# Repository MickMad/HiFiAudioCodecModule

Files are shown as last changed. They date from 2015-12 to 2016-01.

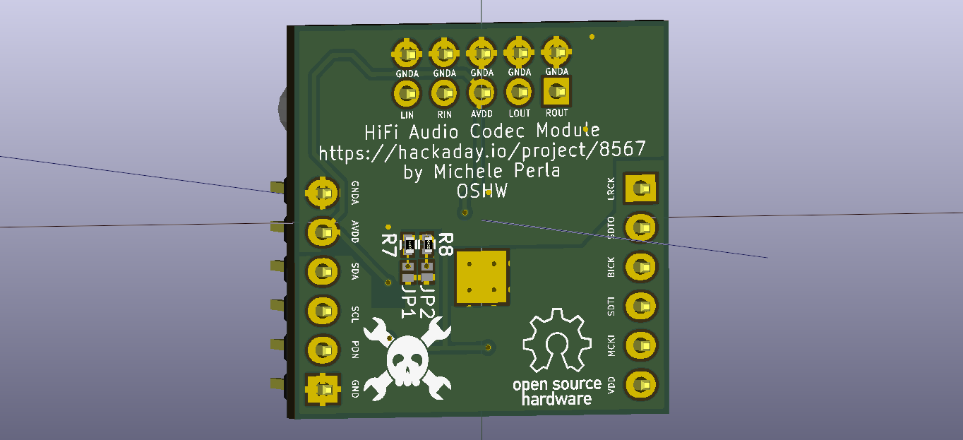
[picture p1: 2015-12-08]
graphics/HiFiAudioCodecModule - 3D - bottom.png

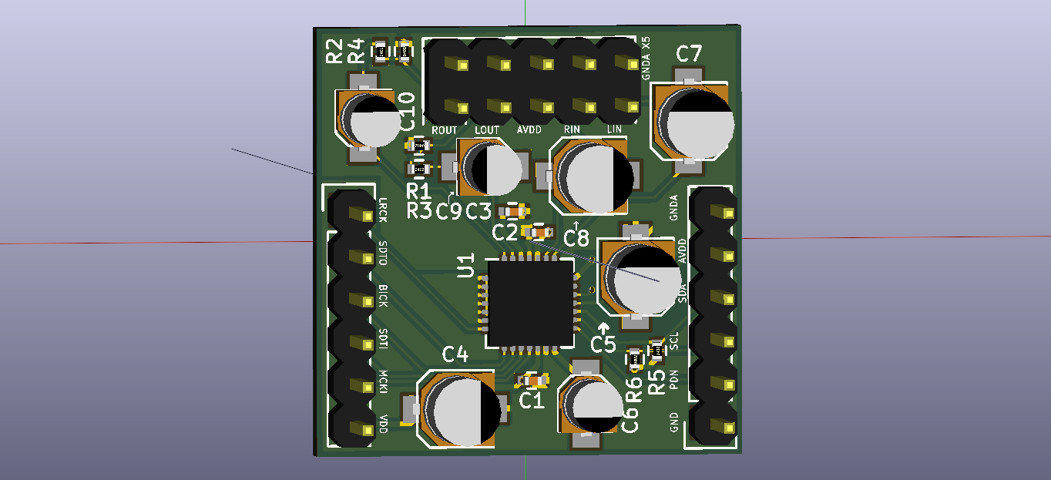
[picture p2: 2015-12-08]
graphics/HiFiAudioCodecModule - 3D - top.png

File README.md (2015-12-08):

#HiFi Audio Codec Module
##A very small hifi audio codec module

The purpose of this project is to create a small (1 square inch board size) HiFi audio CODEC module to be used with I2S-compatible MCUs

More info here: 
https://hackaday.io/project/8567-hifi-audio-codec-module

The project is a submission for the following contest (The Square Inch project): 
https://hackaday.io/project/7813-the-square-inch-project

```
Copyright © Michele Perla 2015

This documentation describes Open Hardware and is licensed under the CERN OHL v. 1.2.
You may redistribute and modify this documentation under the terms of the CERN OHL v.1.2. 
(http://ohwr.org/cernohl). This documentation is distributed
WITHOUT ANY EXPRESS OR IMPLIED WARRANTY, INCLUDING OF
MERCHANTABILITY, SATISFACTORY QUALITY AND FITNESS FOR A
PARTICULAR PURPOSE. Please see the CERN OHL v.1.2 for applicable
conditions
```

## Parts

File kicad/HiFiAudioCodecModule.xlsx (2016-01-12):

 |  |  |  |  |  |  | Board Qty: | 100
 |  |  |  |  |  |  | Total Cost: | $0.00 |  |  |  | $0.00 |  |  |  |  |  | $0.00 |  |  |  |  |  | $0.00
 |  |  |  |  |  |  | Unit Cost: | $0.00
Global Part Info |  |  |  |  |  |  |  |  | Digi-Key |  |  |  |  |  | Mouser |  |  |  |  |  | Newark
Refs | Value | Desc | Footprint | Manf | Manf# | Qty | Unit$ | Ext$ | Avail | Purch | Unit$ | Ext$ | Cat# | Doc | Avail | Purch | Unit$ | Ext$ | Cat# | Doc | Avail | Purch | Unit$ | Ext$ | Cat# | Doc
JP1,JP2 | Jumper_NO_Small |  | HiFiAudioCodecModule-footprints:SMD_Jumper |  |  | 0 | $0.00 | $0.00
LOGO1 | OSHW |  | oshw_logo:LOGO |  |  | 0 | $0.00 | $0.00
C3 | 1u |  | HiFiAudioCodecModule-footprints:C_0402 |  | CC0402KRX7R5BB105 | 0 | $0.00 | $0.00 | 1 |  | $0.00 | $0.00 | 311-1702-1-ND | Link (http://www.digikey.com/product-detail/en/CC0402KRX7R5BB105/311-1702-1-ND/5195604) | 0 |  | $0.00 | $0.00 | 603-CC402KRX7R5BB105 | Link (http://www.mouser.com/Search/Refine.aspx?Keyword=CC0402KRX7R5BB105) | 0 |  | $0.00 | $0.00 | 55X1892 | Link (http://www.newark.com/webapp/wcs/stores/servlet/Search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)
P1,P2 | CONN_01X06 |  | HiFiAudioCodecModule-footprints:Pin_Header_Straight_1x06 |  | M20-9990645 | 0 | $0.00 | $0.00 | 13820 |  | $0.00 | $0.00 | 952-2269-ND | Link (http://www.digikey.com/scripts/DkSearch/dksus.dll?WT.z_header=search_go&lang=en&keywords=M20-9990645) | 6668 |  | $0.00 | $0.00 | 855-M20-9990645 | Link (http://www.mouser.com/Search/Refine.aspx?Keyword=M20-9990645) | 8231 |  | $0.00 | $0.00 | 97K6212 | Link (http://www.newark.com/webapp/wcs/stores/servlet/Search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)
R1,R2 | 220 |  | HiFiAudioCodecModule-footprints:R_0402 |  | RC0402FR-07220RL | 0 | $0.00 | $0.00 | 345265 |  | $0.00 | $0.00 | 311-220LRCT-ND | Link (http://www.digikey.com/product-detail/en/RC0402FR-07220RL/311-220LRCT-ND/729512) | 135033 |  | $0.00 | $0.00 | 603-RC0402FR-07220RL | Link (http://www.mouser.com/Search/Refine.aspx?Keyword=RC0402FR-07220RL) | 12940 |  | $0.00 | $0.00 | 67R9914 | Link (http://www.newark.com/yageo/rc0402fr-07220rl/res-thick-film-220r-1-0-0625w/dp/67R9914)
R5-R8 | 1K |  | HiFiAudioCodecModule-footprints:R_0402 |  | RC0402FR-071KL | 0 | $0.00 | $0.00 | 4418858 |  | $0.00 | $0.00 | 311-1.00KLRCT-ND | Link (http://www.digikey.com/product-detail/en/RC0402FR-071KL/311-1.00KLRCT-ND/729460) | 995543 |  | $0.00 | $0.00 | 603-RC0402FR-071KL | Link (http://www.mouser.com/Search/Refine.aspx?Keyword=RC0402FR-071KL) | 7873 |  | $0.00 | $0.00 | 67R9877 | Link (http://www.newark.com/yageo/rc0402fr-071kl/res-thick-film-1k-1-0-0625w-0402/dp/67R9877)
C4,C5 | 10u |  | HiFiAudioCodecModule-footprints:CAP_ELEC_SMD_3x5mm |  | UWX1C100MCL2GB | 0 | $0.00 | $0.00 | 147265 |  | $0.00 | $0.00 | 493-2099-1-ND | Link (http://www.digikey.com/product-detail/en/UWX1C100MCL2GB/493-2099-1-ND/590074) | 23076 |  | $0.00 | $0.00 | 647-UWX1C100MCL2 | Link (http://www.mouser.com/Search/Refine.aspx?Keyword=UWX1C100MCL2GB) | 1079 |  | $0.00 | $0.00 | 58R3619 | Link (http://www.newark.com/nichicon/uwx1c100mcl2gb/aluminum-electrolytic-capacitor/dp/58R3619)
U1 | AK4558EN |  | HiFiAudioCodecModule-footprints:QFN-28-2xEP_5x5mm_Pitch0.5mm |  | AK4558EN | 0 | $0.00 | $0.00 | 2833 |  | $0.00 | $0.00 | 974-1083-1-ND | Link (http://www.digikey.com/product-detail/en/AK4558EN/974-1083-1-ND/5322946)
LOGO2 | HACKADAY |  | hackaday_logo:LOGO |  |  | 0 | $0.00 | $0.00
C7,C8 | 10u |  | HiFiAudioCodecModule-footprints:C_Radial_D5_L11_P2-bipolar |  | UES1E100MDM1TD | 0 | $0.00 | $0.00 | 9451 |  | $0.00 | $0.00 | 493-10824-1-ND | Link (http://www.digikey.com/product-detail/en/UES1E100MDM1TD/493-10824-1-ND/4317799) | 1858 |  | $0.00 | $0.00 | 647-UES1E100MDM1TD | Link (http://www.mouser.com/Search/Refine.aspx?Keyword=UES1E100MDM1TD) | 0 |  | $0.00 | $0.00 | 58R7475 | Link (http://www.newark.com/webapp/wcs/stores/servlet/Search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)
C1,C2 | 0.1u |  | HiFiAudioCodecModule-footprints:C_0402 |  | CC0402KRX7R7BB104 | 0 | $0.00 | $0.00 | 2903130 |  | $0.00 | $0.00 | 311-1338-1-ND | Link (http://www.digikey.com/product-detail/en/CC0402KRX7R7BB104/311-1338-1-ND/2103122) | 335519 |  | $0.00 | $0.00 | 603-CC402KRX7R7BB104 | Link (http://www.mouser.com/Search/Refine.aspx?Keyword=CC0402KRX7R7BB104) | 45881 |  | $0.00 | $0.00 | 68R4640 | Link (http://www.newark.com/yageo/cc0402krx7r7bb104/ceramic-capacitor-0-1uf-16v-x7r/dp/68R4640)
R3,R4 | 20K |  | HiFiAudioCodecModule-footprints:R_0402 |  | RC0402FR-0720KL | 0 | $0.00 | $0.00 | 1036488 |  | $0.00 | $0.00 | 311-20.0KLRCT-ND | Link (http://www.digikey.com/product-detail/en/RC0402FR-0720KL/311-20.0KLRCT-ND/729504) | 168394 |  | $0.00 | $0.00 | 603-RC0402FR-0720KL | Link (http://www.mouser.com/Search/Refine.aspx?Keyword=RC0402FR-0720KL) | 14523 |  | $0.00 | $0.00 | 67R9906 | Link (http://www.newark.com/yageo/rc0402fr-0720kl/res-thick-film-20k-1-0-0625w-0402/dp/67R9906)
C6 | 1u |  | HiFiAudioCodecModule-footprints:CAP_ELEC_SMD_3x5mm |  | UWX1C100MCL2GB | 0 | $0.00 | $0.00 | 147265 |  | $0.00 | $0.00 | 493-2099-1-ND | Link (http://www.digikey.com/product-detail/en/UWX1C100MCL2GB/493-2099-1-ND/590074) | 23076 |  | $0.00 | $0.00 | 647-UWX1C100MCL2 | Link (http://www.mouser.com/Search/Refine.aspx?Keyword=UWX1C100MCL2GB) | 1079 |  | $0.00 | $0.00 | 58R3619 | Link (http://www.newark.com/nichicon/uwx1c100mcl2gb/aluminum-electrolytic-capacitor/dp/58R3619)
C9,C10 | 1u |  | HiFiAudioCodecModule-footprints:C_Radial_D5_L11_P2-bipolar |  | UES1H010MDM1TD | 0 | $0.00 | $0.00 | 1424 |  | $0.00 | $0.00 | 493-10834-1-ND | Link (http://www.digikey.com/product-detail/en/UES1H010MDM1TD/493-10834-1-ND/4317808) | 0 |  | $0.00 | $0.00 | 647-UES1H010MDM1TD | Link (http://www.mouser.com/Search/Refine.aspx?Keyword=UES1H010MDM1TD) | 0 |  | $0.00 | $0.00 | 58R7486 | Link (http://www.newark.com/webapp/wcs/stores/servlet/Search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)
P3 | CONN_02X05 |  | HiFiAudioCodecModule-footprints:Pin_Header_Straight_2x05 |  | M20-9980545 | 0 | $0.00 | $0.00 | 2083 |  | $0.00 | $0.00 | 952-2380-ND | Link (http://www.digikey.com/scripts/DkSearch/dksus.dll?WT.z_header=search_go&lang=en&keywords=M20-9980545) | 2354 |  | $0.00 | $0.00 | 855-M20-9980545 | Link (http://www.mouser.com/Search/Refine.aspx?Keyword=M20-9980545) | 1011 |  | $0.00 | $0.00 | 56K0014 | Link (http://www.newark.com/webapp/wcs/stores/servlet/Search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)
 |  |  |  |  |  |  |  |  |  | 0 | 0 | 0 |  |  |  | 0 | 0 | 0 |  |  |  | 0 | 0 | 0
 |  |  |  |  |  |  |  |  |  | 0 | 0 | 0 |  |  |  | 0 | 0 | 0 |  |  |  | 0 | 0 | 0
 |  |  |  |  |  |  |  |  |  | 0 | 0 | 0 |  |  |  | 0 | 0 | 0 |  |  |  | 0 | 0 | 0
 |  |  |  |  |  |  |  |  |  | 0 | 0 | 0 |  |  |  | 0 | 0 | 0 |  |  |  | 0 | 0 | 0
 |  |  |  |  |  |  |  |  |  | 0 | 0 | 0 |  |  |  | 0 | 0 | 0 |  |  |  | 0 | 0 | 0
 |  |  |  |  |  |  |  |  |  | 0 | 0 | 0 |  |  |  | 0 | 0 | 0 |  |  |  | 0 | 0 | 0
 |  |  |  |  |  |  |  |  |  | 0 | 0 | 0 |  |  |  | 0 | 0 | 0 |  |  |  | 0 | 0 | 0
 |  |  |  |  |  |  |  |  |  | 0 | 0 | 0 |  |  |  | 0 | 0 | 0 |  |  |  | 0 | 0 | 0
 |  |  |  |  |  |  |  |  |  | 0 | 0 | 0 |  |  |  | 0 | 0 | 0 |  |  |  | 0 | 0 | 0
 |  |  |  |  |  |  |  |  |  | 0 | 0 | 0 |  |  |  | 0 | 0 | 0 |  |  |  | 0 | 0 | 0
 |  |  |  |  |  |  |  |  |  | 0 | 0 | 0 |  |  |  | 0 | 0 | 0 |  |  |  | 0 | 0 | 0
 |  |  |  |  |  |  |  |  |  | 0 | 0 | 0 |  |  |  | 0 | 0 | 0 |  |  |  | 0 | 0 | 0
 |  |  |  |  |  |  |  |  |  | 0 | 0 | 0 |  |  |  | 0 | 0 | 0 |  |  |  | 0 | 0 | 0
 |  |  |  |  |  |  |  |  |  | 0 | 0 | 0 |  |  |  | 0 | 0 | 0 |  |  |  | 0 | 0 | 0
 |  |  |  |  |  |  |  |  |  | 0 | 0 | 0 |  |  |  | 0 | 0 | 0 |  |  |  | 0 | 0 | 0

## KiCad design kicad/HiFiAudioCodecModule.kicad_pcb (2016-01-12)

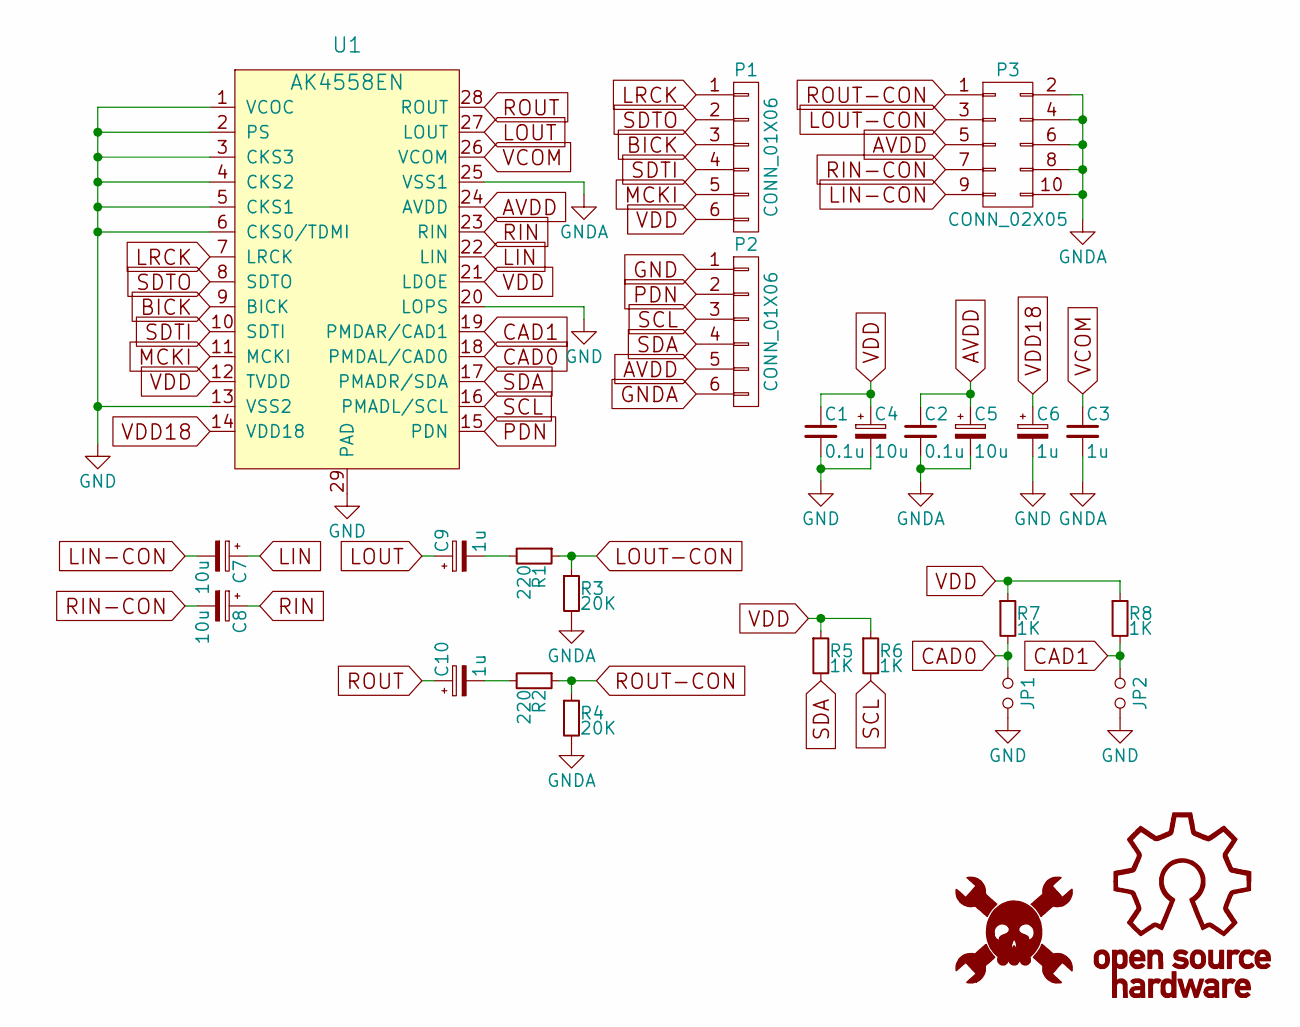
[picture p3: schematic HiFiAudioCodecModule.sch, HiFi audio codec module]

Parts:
C1, C2: 0.1u; C_0402
C3: 1u; C_0402
C4, C5: 10u; CAP_ELEC_SMD_3x5mm
C6: 1u; CAP_ELEC_SMD_3x5mm
C7, C8: 10u; C_Radial_D5_L11_P2-bipolar
C9, C10: 1u; C_Radial_D5_L11_P2-bipolar
JP1, JP2: Jumper_NO_Small; SMD_Jumper
LOGO1: OSHW; LOGO
LOGO2: HACKADAY; LOGO
P1, P2: CONN_01X06; Pin_Header_Straight_1x06
P3: CONN_02X05; Pin_Header_Straight_2x05
R1, R2: 220; R_0402
R3, R4: 20K; R_0402
R5, R6, R7, R8: 1K; R_0402
U1: AK4558EN; QFN-28-2xEP_5x5mm_Pitch0.5mm

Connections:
AVDD: C2.1, C5.1, P2.5, P3.5, U1.24 (AVDD)
BICK: P1.3, U1.9 (BICK)
CAD0: JP1.1, R7.2, U1.18 (PMDAL/CAD0)
CAD1: JP2.1, R8.2, U1.19 (PMDAR/CAD1)
GND: C1.2, C4.2, C6.2, JP1.2, JP2.2, P2.1, U1.1 (VCOC), U1.2 (PS), U1.3 (CKS3), U1.4 (CKS2), U1.5 (CKS1), U1.6 (CKS0/TDMI), U1.13 (VSS2), U1.20 (LOPS), U1.29 (PAD)
GNDA: C2.2, C3.2, C5.2, P2.6, P3.2, P3.4, P3.6, P3.8, P3.10, R3.2, R4.2, U1.25 (VSS1)
LIN: C7.1, U1.22 (LIN)
LIN-CON: C7.2, P3.9
LOUT: C9.1, U1.27 (LOUT)
LOUT-CON: P3.3, R1.1, R3.1
LRCK: P1.1, U1.7 (LRCK)
MCKI: P1.5, U1.11 (MCKI)
unnamed: C9.2, R1.2
unnamed: C10.2, R2.2
PDN: P2.2, U1.15 (PDN)
RIN: C8.1, U1.23 (RIN)
RIN-CON: C8.2, P3.7
ROUT: C10.1, U1.28 (ROUT)
ROUT-CON: P3.1, R2.1, R4.1
SCL: P2.3, R6.2, U1.16 (PMADL/SCL)
SDA: P2.4, R5.2, U1.17 (PMADR/SDA)
SDTI: P1.4, U1.10 (SDTI)
SDTO: P1.2, U1.8 (SDTO)
VCOM: C3.1, U1.26 (VCOM)
VDD: C1.1, C4.1, P1.6, R5.1, R6.1, R7.1, R8.1, U1.12 (TVDD), U1.21 (LDOE)
VDD18: C6.1, U1.14 (VDD18)

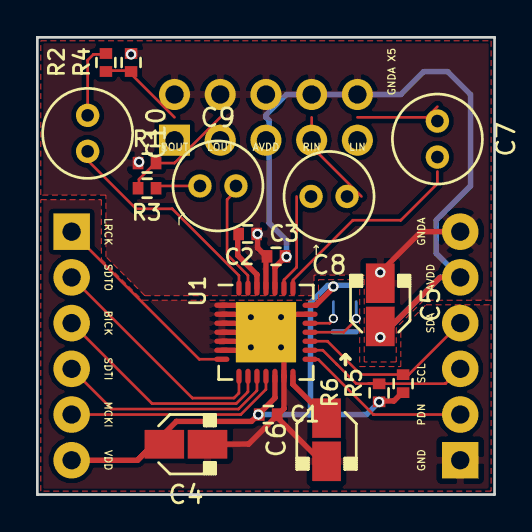
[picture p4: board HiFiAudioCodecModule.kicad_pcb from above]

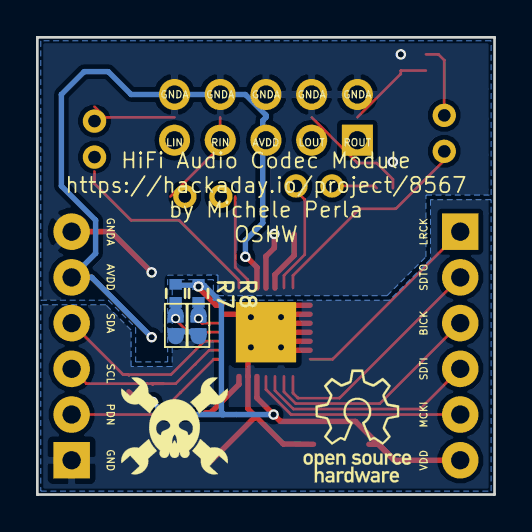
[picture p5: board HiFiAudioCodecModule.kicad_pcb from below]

Board: 2 copper layers, 25.4 x 25.4 mm, 26 parts (6 on the bottom side), 26 nets.

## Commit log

2015-12-08 First commit
    Pushed all files to github in order to be compliant with the Square Inch
    Project rules
    [HiFiAudioCodecModule-B_Cu.gbr, HiFiAudioCodecModule-B_Mask.gbr, HiFiAudioCodecModule-B_SilkS.gbr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]
2015-12-08 Revised PCB page layout
    Revised PCB page layout
    [HiFiAudioCodecModule.kicad_pcb]
2016-01-12 Added manf#s in schematic, fixed footprints, preparing rev.2
    Preparing rev.2 layout:
    -added manf# to check prices for manufacture w/ KiCost
    -changed in/out decoupling caps to thru-hole bipolar audio caps
    (Nichicon)
    -reduced real estate requirements for bypass caps (all 3 mm dia. caps)
    NOTE:LAYOUT COMPROMISED, STILL NEEDS TO BE FIXED
    [HiFiAudioCodecModule.kicad_pcb, HiFiAudioCodecModule.sch, HiFiAudioCodecModule.xlsx]
